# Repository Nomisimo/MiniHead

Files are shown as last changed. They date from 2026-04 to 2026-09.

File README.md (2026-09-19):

# 💡 Mini LED Moving Head

> A DIY mini LED moving head controller based on the ESP32-C3 microcontroller.

---

## 📋 Hardware

| Component | Model |
|---|---|
| Microcontroller | ESP32-C3 Super Mini |
| LED | WS2812B RGBW (1 pixel) |
| Pan servo | TS90MD |
| Tilt servo | TS90MD |

---

## 🚀 Quick Start

```bash
git clone https://github.com/Nomisimo/MiniHead.git
```

→ Current firmware: **[MiniHead](Firmware/MiniHead/README.md)**

---

## 📖 Wiki

- [Feature Map](https://github.com/Nomisimo/MiniHead/wiki/Feature-Map)
- [Firmware Versions](https://github.com/Nomisimo/MiniHead/wiki/Firmware-Versions)

---

## 🙏 Credits

- **cooke001** — [miniTheatreProject](https://github.com/cooke001/miniTheatreProject) (inspiration & foundation)
- **mathieucarbou** — [ESPAsyncWebServer](https://github.com/mathieucarbou/ESPAsyncWebServer) / [AsyncTCP](https://github.com/mathieucarbou/AsyncTCP) (IDF 5.x compatible forks)

> Art-Net™ is a trademark of Artistic Licence Holdings Ltd.

---

## 📜 License

**GNU General Public License v3.0** — [LICENSE](./LICENSE)

---

*Vibe coded with [Claude Code](https://claude.ai/code)*

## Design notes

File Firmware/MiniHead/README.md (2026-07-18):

# MiniHead Firmware — Modular v4.2

> Current recommended firmware for all new installations.  
> LittleFS JSON · ESPAsyncWebServer · Art-Net/DMX512 · Multi-Head UDP · BLE Provisioning

---

## Table of Contents

1. [Features](#1-features)
2. [Hardware](#2-hardware)
3. [Arduino IDE Setup](#3-arduino-ide-setup)
   - [3.1 Install Arduino IDE](#31-install-arduino-ide)
   - [3.2 Add ESP32 Board Package](#32-add-esp32-board-package)
   - [3.3 Install Libraries](#33-install-libraries)
   - [3.4 Board & Tools Settings](#34-board--tools-settings)
4. [Project Configuration — config.h](#4-project-configuration--configh)
5. [Flashing](#5-flashing)
6. [Code Structure](#6-code-structure)
   - [6.1 Entry Point](#61-entry-point--mainoino)
   - [6.2 Plugin System](#62-plugin-system)
   - [6.3 Core Hardware Layer](#63-core-hardware-layer--coreh)
   - [6.4 Plugin Overview](#64-plugin-overview)
7. [UI Themes](#7-ui-themes)
8. [HTTP API Reference](#8-http-api-reference)
   - [8.1 Control](#81-control)
   - [8.2 Cues & Sequencer](#82-cues--sequencer)
   - [8.3 Fixtures & Network](#83-fixtures--network)
   - [8.4 Art-Net Patch](#84-art-net-patch)
   - [8.5 Configuration](#85-configuration)
9. [UDP Protocol](#9-udp-protocol)
10. [Art-Net / DMX512](#10-art-net--dmx512)
11. [BLE Provisioning](#11-ble-provisioning)
12. [PC Leader App](#12-pc-leader-app)
13. [Art-Net Test Tool](#13-art-net-test-tool)
14. [Stored Files — LittleFS](#14-stored-files--littlefs)
15. [Serial Monitor — Boot Output](#15-serial-monitor--boot-output)

---

## 1. Features

| Feature | Detail |
|---|---|
| **Web UI** | Full control panel served directly from the ESP at `http://<ip>` — no app needed |
| **Multi-head network** | Leader/follower election by lowest MAC; PC Leader App always wins |
| **Cues + Sequencer** | Up to 32 saved scenes, per-fixture targeting, timed playback with loop |
| **Art-Net / DMX512** | Built-in WiFiUDP parser, 7-channel fixture footprint, no external library |
| **BLE Provisioning** | Zero-touch WiFi credential distribution via Bluetooth GATT |
| **LittleFS JSON storage** | All settings in human-readable `.json` files; survives firmware updates |
| **ESPAsyncWebServer** | Non-blocking HTTP; servo commands respond in < 5 ms |
| **WiFi multi-network** | Tries last-connected SSID first, falls back down a list |
| **Theme system** | Swap the full UI look by renaming a header file and reflashing |
| **Servo smoothing** | Exponential smoothing at 50 Hz with deadband — silent, jitter-free |
| **Debugger plugin** | Optional: log config UI + loop frequency, heap, FreeRTOS task stats over Serial |

---

## 2. Hardware

| Component | Model | Pin |
|---|---|---|
| Microcontroller | ESP32-C3 Super Mini (RISC-V, single-core) | — |
| LED | WS2812B RGBW, 1 pixel | GPIO 8 |
| Pan servo | SG90 | GPIO 2 |
| Tilt servo | SG90 | GPIO 3 |
| Power | 5 V, ≥ 1 A shared rail for LED + servos | — |

> **USB CDC:** The ESP32-C3 Super Mini uses an integrated USB serial bridge — no external USB-UART adapter needed. **USB CDC On Boot must be Enabled** in Arduino IDE (see §3.4).

---

## 3. Arduino IDE Setup

### 3.1 Install Arduino IDE

Download **Arduino IDE 2.x** from https://www.arduino.cc/en/software

### 3.2 Add ESP32 Board Package

1. **File → Preferences** (macOS: **Arduino IDE → Settings**)
2. Paste into *Additional boards manager URLs*:
   ```
   https://raw.githubusercontent.com/espressif/arduino-esp32/gh-pages/package_esp32_index.json
   ```
3. **Tools → Board → Boards Manager** → search `esp32` → install **"esp32" by Espressif Systems** version **3.x**

> ⚠️ **Version 3.x is required.** Version 2.x is not compatible with the async web server fork used here.

### 3.3 Install Libraries

#### Via Library Manager (`Tools → Manage Libraries`)

| Library | Author | Notes |
|---|---|---|
| **Adafruit NeoPixel** | Adafruit | RGBW LED driver |
| **ESP32Servo** | Kevin Harrington | Servo PWM on ESP32 |
| **ArduinoJson** | Benoit Blanchon | JSON for LittleFS files and API |

> **Remove if installed (no longer needed):**
> - **ArtnetWifi** — replaced with a custom WiFiUdp parser in `artnet_receiver.h` (no external library dependency)
> - **Adafruit DMA NeoPixel** — DMA variant for SAMD21/SAMD51 only; never applicable to ESP32-C3

#### Via ZIP Install — AsyncTCP + ESPAsyncWebServer

The standard Library Manager version of ESPAsyncWebServer is **incompatible with Arduino Core 3.x**. Use the **mathieucarbou fork** exclusively.

**Download these ZIPs:**

| Library | URL |
|---|---|
| AsyncTCP | https://github.com/mathieucarbou/AsyncTCP/archive/refs/heads/main.zip |
| ESPAsyncWebServer | https://github.com/mathieucarbou/ESPAsyncWebServer/archive/refs/heads/main.zip |

**Install:** `Sketch → Include Library → Add .ZIP Library…` — install **AsyncTCP first**, then ESPAsyncWebServer.

**Remove old versions first** (if previously installed via Library Manager): delete their folders from `~/Documents/Arduino/libraries/`.

#### Libraries that come with ESP32 Arduino Core (no install needed)

These are part of the ESP32 board package and available automatically:

- `WiFi.h`, `WiFiUdp.h` — WiFi STA/AP + UDP sockets
- `ESPmDNS.h` — mDNS (`minihead.local`)
- `DNSServer.h` — Captive portal DNS
- `LittleFS.h` — Flash file system
- `BLEDevice.h`, `BLEServer.h`, `BLEClient.h`, `BLEScan.h`, … — Bluetooth GATT (BLE provisioning)
- `freertos/FreeRTOS.h`, `task.h` — RTOS tasks (BLE provisioning sender)
- `mbedtls/aes.h`, `mbedtls/md.h` — Crypto (BLE provisioning)

### 3.4 Board & Tools Settings

Set these in the **Tools** menu before every upload:

| Setting | Value |
|---|---|
| **Board** | `ESP32C3 Dev Module` |
| **USB CDC On Boot** | `Enabled` ← **required for Serial Monitor** |
| **CPU Frequency** | `160 MHz` |
| **Flash Frequency** | `80 MHz` |
| **Flash Mode** | `QIO` |
| **Flash Size** | `4MB (32Mb)` |
| **Partition Scheme** | `Huge APP (3MB No OTA/1MB SPIFFS` |
| **Upload Speed** | `921600` |
| **Port** | your ESP32's USB port |

> **Partition Scheme is mandatory.** LittleFS uses the SPIFFS partition slot. Without this, the device boots but cannot save settings — cues, patches, and WiFi memory are lost on every reset.

**Finding your port:**
- macOS: `/dev/cu.usbmodem…` or `/dev/cu.SLAB_USBtoUART`
- Windows: `COM3`, `COM4`, … (Device Manager)
- Linux: `/dev/ttyUSB0` or `/dev/ttyACM0`

macOS CH34x driver (if port doesn't appear): https://github.com/WCHSoftGroup/ch34xser_macos

---

## 4. Project Configuration — config.h

`config.h` is **git-ignored** — copy the template first:

```bash
cp config.example.h config.h
```

`config.h` is the **only file you normally need to edit**. It controls which plugins are active and what WiFi networks to try. Here's the complete annotated file:

```cpp
// ── Plugin flags ──────────────────────────────────────────────────
// Uncomment to enable. Order here does NOT matter — plugins register
// themselves via static initializers. Execution order in main.ino is
// determined by the #include order below.

//#define PLUGIN_STARTUP_ANIMATION  // Servo sweep + color test on first boot
//#define PLUGIN_UDP_CONTROL        // Multi-head UDP discovery + leader election
//#define PLUGIN_ARTNET             // Art-Net / DMX512 receiver
//#define PLUGIN_DEBUGGER           // Log config UI + loop timing + heap stats (must be last)
//#define PLUGIN_BLE_PROVISION      // BLE GATT WiFi credential distribution

// ── WiFi network list ─────────────────────────────────────────────
// The ESP tries networks in this order (last-connected SSID gets
// priority on next boot). Leave empty if using BLE provisioning.
struct WifiCredential { const char* ssid; const char* password; };
static const WifiCredential WIFI_NETWORKS[] = {
  { "PrimarySSID",  "password1" },
  { "BackupSSID",   "password2" },  // optional fallback
};
static const int WIFI_NETWORK_COUNT =
    sizeof(WIFI_NETWORKS) / sizeof(WIFI_NETWORKS[0]);

// ── AP hotspot password ───────────────────────────────────────────
// Used when no known WiFi is reachable. Must be ≥ 8 chars, or "" for open.
#define AP_PASSWORD ""

// ── BLE Provisioning ─────────────────────────────────────────────
// 32 hex chars = 16-byte AES-128 key. All devices in the fleet must
// share the same key. Change before flashing — never leave as zeros.
#define PROVISION_KEY "00000000000000000000000000000000"
```

**WiFi boot sequence:**
1. Read `/wifi_saved.json` (BLE-provisioned credentials) and try alongside `WIFI_NETWORKS[]`
2. Read `/wifi_last.json` — try that SSID first if visible
3. Try remaining entries in order, then without scan filter (hidden SSIDs)
4. After 2 failed cycles → start AP hotspot `MiniHead-XXYY` at `192.168.4.1` *(Standalone mode only; UDP/Art-Net devices retry forever)*

**Changing config.h always requires a full re-upload** (it's compiled in). LittleFS data (cues, patches, names) is preserved across uploads.

---

## 5. Flashing

1. Connect ESP32-C3 via USB-C
2. Open `main/main.ino` in Arduino IDE
3. Verify Tools settings (§3.4) and select the correct port
4. Click **Upload** or press **Ctrl+U / Cmd+U**

Watch the console for:
```
Wrote 123456 bytes ...
Hash of data verified.
Hard resetting via RTS pin...
```

Open **Tools → Serial Monitor** at **115200 baud** and press the reset button. See §15 for expected output.

> Re-flash whenever you change `config.h`, pins, or any `#define`. LittleFS data survives.

---

## 6. Code Structure

```
main/
├── main.ino                         ← Entry point (setup + loop) — never touch this
├── config.h                         ← Your configuration (git-ignored)
├── config.example.h                 ← Template for config.h
├── core.h                           ← Hardware drivers: LED, servos, animations
├── core_globals.h                   ← extern declarations shared across plugins
├── plugin_registry.h                ← REGISTER_PLUGIN macro + _plugins[] table
└── plugins/
    ├── storage/
    │   └── storage.h                ← LittleFS mount + readJson/writeJson helpers
    ├── startup_animation/
    │   └── startup_animation.h      ← Servo sweep + color test (optional)
    ├── wifi/
    │   ├── wifi.h                   ← Plugin entry point
    │   ├── wifi_control.h           ← ESPAsyncWebServer, all HTTP routes, cues, sequencer
    │   ├── discovery.h              ← UDP beacon broadcast + leader/follower election
    │   ├── discovery_globals.h      ← Shared types: NodeRole, Peer, MAC, ports
    │   ├── discovery_stubs.h        ← Empty stubs when PLUGIN_UDP_CONTROL is off
    │   ├── html_page.h              ← Embedded main UI HTML (PROGMEM, layout only)
    │   ├── theme.h                  ← Active CSS theme (PROGMEM, served at GET /theme)
    │   └── log_config.h             ← Runtime log level struct + load/save (always included)
    ├── udp_control/
    │   ├── udp_control.h            ← Plugin entry point
    │   └── discovery.h              ← Leader election, peer table, UDP CMD dispatcher
    ├── artnet/
    │   ├── artnet.h                 ← Plugin entry point
    │   ├── artnet_globals.h         ← Structs, DMX_FOOTPRINT, ARTNET_PORT
    │   ├── artnet_receiver.h        ← WiFiUDP polling, DMX parsing, apply + relay
    │   ├── artnet_control.h         ← HTTP patch management routes
    │   └── artnet_panel_html.h      ← Art-Net panel HTML
    ├── ble_provision/
    │   ├── ble_provision.h          ← Full BLE GATT provisioning logic (SEEKER + SENDER)
    │   └── ble_provision_config.h   ← BLE service/characteristic UUIDs + timeouts
    ├── debugger/
    │   └── debugger.h               ← Log config HTTP UI + loop timing + heap stats (optional)
    └── shared/
        └── crypto.h                 ← AES-128-CBC + HMAC-SHA256 + key parser (shared)
```

### 6.1 Entry Point — `main.ino`

`main.ino` is intentionally minimal and **never needs to be edited** (plugins are added via `config.h`). What it does:

```
setup():
  core_setup()                → mount LittleFS, init LED + servos
  [ble_provision_pre_wifi()]  → SEEKER blocks here if no credentials (optional, BLE provisioning only)
  wifi_connectMulti()         → connect to WiFi or start AP mode
  WiFi.setSleep(false)          → disable modem sleep for low-latency UDP
  MDNS.begin("minihead")        → accessible as minihead.local
  for each plugin: setup()      → initialize all registered plugins

loop():
  DNS captive portal tick        → handles Android/iOS in AP mode
  core_loop()                   → servo smoothing, rainbow/demo animation
  for each plugin: loop()       → run all plugin loops (HTTP, Art-Net, discovery…)
```

### 6.2 Plugin System

Each plugin lives in its own folder and self-registers via a static C++ initializer before `setup()` runs:

```cpp
// At the bottom of every plugin header:
REGISTER_PLUGIN(wifi);
// expands to:
// static PluginRegistrar _wifi_reg(wifi_setup, wifi_loop);
```

The `PluginRegistrar` constructor appends `{setup, loop}` to the global `_plugins[]` array (max 8 entries). `main.ino` calls them all in registration order without knowing their names.

**To add a plugin:** uncomment its `#define` and `#include` in `config.h`.  
**To remove a plugin:** comment them out. The stubs header keeps link-time symbols valid.

### 6.3 Core Hardware Layer — `core.h`

`core.h` initializes the hardware and exposes global functions used by all plugins:

| Function | Description |
|---|---|
| `core_setup()` | Mount LittleFS, init NeoPixel, attach servos at 50 Hz |
| `core_loop()` | Servo smoothing (every 20 ms), rainbow hue cycle, demo sinusoid |
| `setLED(r, g, b, w)` | Set RGBW LED. No-op if color unchanged (saves NeoPixel interrupt) |
| `setPan(angle)` | Set pan target 0–270°. Smoothed exponentially at 50 Hz |
| `setTilt(angle)` | Set tilt target 0–270° |
| `applyCommand(String)` | Parse and apply a control string (see §9 command format) |

**Servo smoothing:** `next = current + 0.12 × (target − current)` — deadband 1.5° to stop hunting.

**Global state** (readable anywhere via `core_globals.h`):

| Variable | Type | Meaning |
|---|---|---|
| `curR/G/B/W` | `uint8_t` | Current LED color |
| `curPan/curTilt` | `int` | Current servo angle |
| `rainbowActive` | `bool` | Rainbow effect running |
| `demoActive` | `bool` | Demo sinusoid animation |
| `animSpeed` | `float` | Speed multiplier 0.1–3.0× |
| `wifiAPMode` | `bool` | Device is in AP hotspot mode |

### 6.4 Plugin Overview

| Plugin | `#define` | What it does |
|---|---|---|
| **wifi** | always on | HTTP server, web UI, cues, sequencer, leader redirect |
| **startup_animation** | `PLUGIN_STARTUP_ANIMATION` | Servo sweep + RGBW color test on boot |
| **udp_control** | `PLUGIN_UDP_CONTROL` | UDP discovery beacons, leader election, peer table, CMD relay |
| **artnet** | `PLUGIN_ARTNET` | Art-Net DMX512 receiver + HTTP patch management |
| **ble_provision** | `PLUGIN_BLE_PROVISION` | Zero-touch WiFi credential distribution via Bluetooth GATT |
| **debugger** | `PLUGIN_DEBUGGER` | Log config web UI (`/api/logconfig`) + loop stats, heap, FreeRTOS task table over Serial. **Must be last in `config.h`.** |

---

## 7. UI Themes

The web UI separates **layout** (never changes) from **theme** (all colors, fonts, and visual styles). The theme is a CSS file served by the ESP at `GET /theme`.

### Available theme files

| File | Design |
|---|---|
| `theme.h` | **Active theme.** Dark cyberpunk — cyan + purple accents, Share Tech Mono |

### How to switch themes

1. Replace the contents of `theme.h` with your custom CSS (or create a new file and rename it to `theme.h`)
2. Upload firmware

No other changes needed — `wifi_control.h` always serves `theme.h` at `GET /theme`.

### How themes work (CSS variables)

Every theme defines a `:root {}` block with these variables. Components reference only `var(--name)`:

```css
:root {
  /* Backgrounds */
  --bg:        #0a0a0f;   /* page background */
  --surface:   #13131a;   /* card / panel background */
  --surface2:  #1c1c26;   /* secondary surface, inputs */
  --border:    #2a2a3a;   /* dividers, input borders */

  /* Accent colors */
  --accent:    #00e5ff;   /* primary accent (cyan / blue) */
  --accent2:   #ff6b35;   /* secondary accent (orange) */
  --accent3:   #a855f7;   /* tertiary accent (purple) */

  /* Text */
  --text:      #e0e0f0;   /* primary text */
  --text-dim:  #6b6b8a;   /* labels, metadata */

  /* Status */
  --success:   #22c55e;   /* connected, Art-Net active */
  --danger:    #ef4444;   /* error, disconnect */

  /* Typography */
  --mono:      'Share Tech Mono', monospace;
  --sans:      'Barlow', sans-serif;
}
```

To create a custom theme: copy any theme file, rename it to `theme.h`, adjust the `:root` variables to taste, and reflash.

---

## 8. HTTP API Reference

All routes are available at `http://<esp-ip>/`. Responses are `application/json` unless noted.

In AP mode (`192.168.4.1`) the full API is available. Routes guarded by leader-check redirect followers to the leader IP/port.

---

### 8.1 Control

| Method | Path | Body (JSON) | Response | Description |
|---|---|---|---|---|
| `GET` | `/api/status` | — | `{"connected":true,"port":"WiFi","ip":"…","apMode":false,"apPasswordSet":false,"rainbowActive":false,"demoActive":false,"animSpeed":1.0}` | Current device state |
| `GET` | `/api/version` | — | `{"version":"4.2"}` | Firmware version |
| `POST` | `/api/send` | `{"command":"R:255,G:0,B:0,W:0,PAN:90,TILT:45","targets":["AA:BB:CC:DD:EE:FF"]}` | `{"status":"ok"}` | Send a control command. Omit `targets` or pass `[]` for broadcast to all |
| `POST` | `/api/rainbow` | `{"on":true}` | `{"status":"ok"}` | Start or stop the rainbow hue cycle |
| `POST` | `/api/demo` | `{"on":true}` | `{"status":"ok"}` | Start or stop the sinusoid demo animation |
| `POST` | `/api/animation/speed` | `{"speed":1.5}` | `{"status":"ok"}` | Set animation speed multiplier (0.1 – 3.0) |
| `POST` | `/api/blackout` | — | `{"status":"ok"}` | Immediate blackout — LED off, stop all effects |
| `POST` | `/api/ap/password` | `{"password":"mypassword"}` | `{"status":"ok","reconnect":true}` | Set AP hotspot password (≥ 8 chars). Empty string removes it |

**Command string format** (used in `POST /api/send` and UDP CMD):

```
R:0-255,G:0-255,B:0-255,W:0-255,PAN:0-270,TILT:0-270
RAINBOW:0|1
DEMO:0|1
SPEED:0.1-3.0
BLACKOUT
```

Fields are optional and can be combined: `R:255,PAN:90` sets red and pan without touching other channels.

---

### 8.2 Cues & Sequencer

A **cue** is a named scene: RGBW color + pan + tilt + a list of fixture targets.

| Method | Path | Body (JSON) | Response | Description |
|---|---|---|---|---|
| `GET` | `/api/cues` | — | `[{"id":1700000000,"name":"Red Wash","r":255,"g":0,"b":0,"w":0,"pan":90,"tilt":45,"fixTargets":[1,2],"targetCount":2}, …]` | List all saved cues |
| `POST` | `/api/cues` | `{"name":"My Cue","r":255,"g":128,"b":0,"w":0,"pan":90,"tilt":45,"fixTargets":[1]}` | `{"status":"ok","id":1700000001}` | Save current state as a new cue |
| `POST` | `/api/cues/:id/fire` | — | `{"status":"ok"}` | Fire cue immediately to its targets |
| `PUT` | `/api/cues/:id/targets` | `{"fixTargets":[1,2,3]}` | `{"status":"ok"}` | Update which fixtures a cue targets |
| `PUT` | `/api/cues/reorder` | `{"order":[id3,id1,id2]}` | `{"status":"ok"}` | Reorder cues (affects sequencer playback order) |
| `DELETE` | `/api/cues/:id` | — | `{"status":"ok"}` | Delete cue by ID |
| `POST` | `/api/sequencer/start` | `{"interval_ms":2000,"loop":true,"cue_ids":[id1,id2,id3]}` | `{"status":"ok"}` | Start automatic sequence playback |
| `POST` | `/api/sequencer/stop` | — | `{"status":"ok"}` | Stop sequencer |
| `GET` | `/api/sequencer/status` | — | `{"running":false}` | Is sequencer currently playing? |

**Cue limits:** max 32 cues, max 16 fixture targets per cue. `fixTargets:[]` or `fixTargets:[0]` targets all known fixtures. Cues persist in `/cues.json` across reboots.

---

### 8.3 Fixtures & Network

| Method | Path | Body (JSON) | Response | Description |
|---|---|---|---|---|
| `GET` | `/api/heads` | — | `[{"mac":"AA:BB:CC:DD:EE:FF","ip":"192.168.1.100","fixID":1,"name":"Head 1","role":"LEADER","online":true}, …]` | All known heads including self |
| `GET` | `/api/fixtures` | — | `[{"id":1,"name":"Head 1","mac":"AA:BB:CC:DD:EE:FF","ip":"192.168.1.100","online":true}, …]` | Fixtures indexed by fixID |
| `POST` | `/api/heads/:mac/identify` | `{"on":true}` | `{"status":"ok"}` | Flash LED white for 2 s to identify a head |
| `POST` | `/api/heads/:mac/fixid` | `{"fixID":2}` | `{"status":"ok"}` | Set fixture ID on a remote head |
| `POST` | `/api/heads/:mac/name` | `{"name":"Stage Left"}` | `{"status":"ok"}` | Set display name on a remote head |

---

### 8.4 Art-Net Patch

Only available when `PLUGIN_ARTNET` is enabled.

| Method | Path | Body (JSON) | Response | Description |
|---|---|---|---|---|
| `GET` | `/api/artnet/status` | — | `{"active":true,"patchCount":1,"r":255,"g":0,"b":0,"w":0,"pan":90,"tilt":45}` | Art-Net status + live DMX output |
| `GET` | `/api/artnet/patch` | — | `[{"fixID":1,"universe":1,"startAddr":1}]` | Current patch assignments |
| `POST` | `/api/artnet/patch` | `{"universe":1,"startAddr":1}` | `{"status":"ok"}` | Set own patch |
| `PUT` | `/api/artnet/patch/*` | `{"universe":1,"startAddr":8}` | `{"status":"ok"}` | Update universe/address (pass -1 to leave unchanged) |
| `DELETE` | `/api/artnet/patch` | — | `{"status":"ok"}` | Clear all patches |
| `POST` | `/api/artnet/patch/bulk` | `{"universe":1,"startAddr":1,"count":4,"firstFixID":1}` | `{"status":"ok"}` | Auto-assign patches to N consecutive fixtures starting at firstFixID |

> Universe must be **1–32767**. Universe 0 is rejected at all API layers.

**DMX fixture footprint (7 channels):**

| Ch offset | Parameter | Range |
|---|---|---|
| 0 | Master dimmer | 0–255 |
| 1 | Red | 0–255 |
| 2 | Green | 0–255 |
| 3 | Blue | 0–255 |
| 4 | White | 0–255 |
| 5 | Pan | 0–255 → 0–270° |
| 6 | Tilt | 0–255 → 0–270° |

---

### 8.5 Configuration

These routes always operate on the local device (no leader redirect):

| Method | Path | Body (JSON) | Response | Description |
|---|---|---|---|---|
| `POST` | `/api/config/fixid` | `{"fixID":1}` | `{"status":"ok"}` | Set this device's fixture ID (persists to `/discovery.json`) |
| `POST` | `/api/config/name` | `{"name":"Stage Left"}` | `{"status":"ok"}` | Set this device's display name |
| `GET` | `/api/logconfig` | — | log config JSON | Get runtime log levels *(requires `PLUGIN_DEBUGGER`)* |
| `POST` | `/api/logconfig` | log config JSON | `{"status":"ok"}` | Set runtime log levels *(requires `PLUGIN_DEBUGGER`)* |

---

## 9. UDP Protocol

When `PLUGIN_UDP_CONTROL` is enabled, devices broadcast discovery beacons and listen for commands.

### Discovery beacon — port 4210

Sent every 2000 ms as a UTF-8 string broadcast to the subnet:

```
MINIHEAD|AA:BB:CC:DD:EE:FF|192.168.1.100|1|LEADER|Head 1|UDP|100
          ─────MAC──────── ──────IP───── ^ ──────  ──────  ───  ───
                                         fixID    name    mode  priority
```

`mode` is `UDP` or `ARTNET`. `role` is `LEADER` or `FOLLOWER`. `priority`: `0` = PC App, `100` = ESP. Older firmware without the priority field defaults to `100` for backward compatibility.

A peer is considered stale after **90 seconds** without a beacon.

### Commands — port 4211

```
CMD|AA:BB:CC:DD:EE:FF|R:255,G:0,B:0,W:0,PAN:90,TILT:45
     ──target MAC───  ──────command string──────────────
```

Special packets:

```
IDENTIFY_ON|AA:BB:CC:DD:EE:FF    → flash LED white for 2 s
IDENTIFY_OFF|AA:BB:CC:DD:EE:FF   → stop identify immediately
SETPATCH|fixID|universe|addr      → set Art-Net patch on target
```

### Leader election

1. Each device listens on port 4210 for 4 seconds at boot
2. Lowest **priority** wins (`0` = PC App, `100` = ESP); MAC is the tiebreaker among equal-priority nodes — the PC App always beats any ESP
3. Followers redirect their web UI requests to the leader (port 8080 if PC App, port 80 if ESP)
4. If leader goes silent for > 90 s, a new election happens after a 10 s hold

---

## 10. Art-Net / DMX512

Enable with `#define PLUGIN_ARTNET` in `config.h`.

- Listens on UDP port **6454** (Art-Net standard)
- Receives **ArtDMX** packets (opcode `0x5000`)
- Applies channels to the local fixture based on the **patch** (universe + start address)
- Relays commands to peer heads via UDP CMD when Art-Net controls multiple fixtures
- Times out after **8 seconds** without a packet → marks Art-Net inactive, re-enables manual control
- Status bar in the web UI turns green when Art-Net is active; manual sliders gray out

**Setup:**
1. Enable `PLUGIN_ARTNET`, compile, flash
2. Open `http://<esp-ip>` → Art-Net panel → set Universe and Start Address
3. Send Art-Net from a controller (PC App, test tool, DMX desk, etc.)

---

## 11. BLE Provisioning

Enable with `#define PLUGIN_BLE_PROVISION` in `config.h`.

This allows devices with **no WiFi credentials** (empty `WIFI_NETWORKS[]`) to receive the SSID and password wirelessly from a device that is already connected — no USB cable or AP needed for new heads. Uses Bluetooth GATT (frequency-hopping 2.4 GHz) instead of ESP-NOW, so there is **no WiFi channel constraint**.

### Roles

| Role | Condition | Behaviour |
|---|---|---|
| **SEEKER** | `WIFI_NETWORK_COUNT == 0` and no `/wifi_provision.json` and no `/wifi_saved.json` | BLE scan loop; on finding a SENDER: connects, reads characteristic, verifies HMAC, decrypts, saves credentials to `/wifi_provision.json`, reboots |
| **SENDER** | Connected to WiFi via STA | Starts a GATT server in a background task; advertises encrypted SSID+PW for `PROVISION_SENDER_MS`; then deinits BLE automatically |

### Security

- **PROVISION_KEY** (set in `config.h`, 32 hex chars) is used as AES-128-CBC key and HMAC-SHA256 key
- Only devices with the matching key can decrypt the payload
- SSID+PW are AES-128-CBC encrypted with a fresh random IV per payload
- HMAC-SHA256 covers the full payload — integrity and authentication
- Key is never transmitted — only used locally for crypto operations

### Setup

1. Set a real key in `config.h`:
   ```cpp
   #define PROVISION_KEY "a1b2c3d4e5f6a7b8c9d0e1f2a3b4c5d6"
   ```
2. Uncomment `#define PLUGIN_BLE_PROVISION`
3. Flash **all devices** with the same binary
4. One device needs `WIFI_NETWORKS[]` filled in (it becomes the SENDER)
5. Other devices start with empty `WIFI_NETWORKS[]` → they become SEEKERs

### Boot flow with provisioning enabled

```
Device with credentials:            Device without credentials (first time):
  boot → ble_provision_pre_wifi()     boot → ble_provision_pre_wifi()
  → already has creds → no-op         → SEEKER: BLE scan loop
  wifi_connectMulti() → connected       ↓ finds SENDER GATT service
  plugin setup() → SENDER task starts   ↓ reads + verifies payload
  advertises encrypted creds → →      credentials verified (HMAC + AES decrypt)
  stops after PROVISION_SENDER_MS     saved to /wifi_provision.json → reboot
                                        boot → wifi_connectMulti()
                                          reads /wifi_provision.json
                                          copies to /wifi_saved.json (permanent)
                                          deletes /wifi_provision.json
                                        → connected ✓
                                        All subsequent boots: uses /wifi_saved.json
                                        plugin_setup() → also SENDER now
```

---

## 12. PC Leader App

`PC App/server.py` — Python/Flask server that acts as the permanent network leader. ESP devices detect it and yield to it automatically.

### Requirements

```bash
pip install flask
```

### Start

```bash
cd "PC App"
python3 server.py
```

Open **http://localhost:8080**

### What it does

| Function | Detail |
|---|---|
| Leader beacon | UDP broadcast every 1 s → ESP yields to PC |
| Peer discovery | Reads ESP beacons → builds peer table |
| Full web UI | Control all heads from `http://localhost:8080` |
| Art-Net sniffer | Monitors UDP 6454 for live DMX |
| Patch push | Sends `SETPATCH` UDP to ESP when patch changes |
| Auto-redirect | Visiting `http://<esp-ip>` while PC App is running redirects to `http://127.0.0.1:8080` |

---

## 13. Art-Net Test Tool

`PC APP/artnet_test.py` — standalone DMX sender with a browser UI for testing fixtures.

```bash
pip install flask
python3 artnet_test.py                             # broadcast
python3 artnet_test.py 192.168.1.100 0 1           # unicast to IP, universe 0, addr 1
python3 artnet_test.py 192.168.1.255 0 1 --bind 192.168.1.50  # force outgoing interface
```

Open **http://localhost:8765**

| Terminal key | Action |
|---|---|
| `SPACE` | Toggle demo mode |
| `n` | Toggle rainbow |
| `0` | Blackout |
| `f` | Full white |
| `p / P` | Pan ± 10 |
| `t / T` | Tilt ± 10 |
| `r/g/b/w` / `R/G/B/W` | Color channel ± 10 |
| `m / M` | Master ± 10 |
| `q` | Quit |

---

## 14. Stored Files — LittleFS

All files survive firmware uploads. To wipe, use **Tools → ESP32 Sketch Data Upload** with an empty data folder, or call `LittleFS.format()` once.

| File | Format | Contents |
|---|---|---|
| `/wifi_last.json` | `{"ssid":"YourSSID"}` | Last successfully connected SSID |
| `/wifi_provision.json` | `{"ssid":"…","pass":"…"}` | One-time BLE provisioning transport — deleted on first successful connect after credentials are copied to `/wifi_saved.json` |
| `/wifi_saved.json` | `{"ssid":"…","pass":"…"}` | Permanent BLE-provisioned credentials — used on every boot like a runtime `WIFI_NETWORKS[]` entry |
| `/discovery.json` | `{"fixID":1,"name":"Head 1"}` | Fixture ID and display name |
| `/cues.json` | JSON array | Up to 32 saved cues |
| `/artnet.json` | JSON array | Art-Net patch assignments |
| `/config.json` | `{"apPassword":"…"}` | AP password override (set via API) |

---

## 15. Serial Monitor — Boot Output

Set baud to **115200**. Press the reset button after opening.

**Successful STA connect:**
```
[Storage] LittleFS OK
[Core] LED + Servos ready
[WiFi] Scanning...
[WiFi] Connected: YourSSID  IP: 192.168.1.100
[Discovery] MAC: AA:BB:CC:DD:EE:FF  FixID: 1
[Discovery] Listening 4 s for existing leader...
[Discovery] ** I am the LEADER **
[WiFi] Async server started
[ArtNet] Listening on port 6454
```

**AP mode fallback:**
```
[WiFi] All networks failed (2/2)
[WiFi] AP mode — SSID: MiniHead-EEFF  IP: 192.168.4.1
[WiFi] Captive portal DNS started
[WiFi] mDNS: minihead.local
```

**SEEKER provisioning (first boot, no credentials):**
```
[PROVISION] No credentials — SEEKER mode (BLE scan)
[PROVISION] SEEKER BLE scan...
[PROVISION] SENDER found: AA:BB:CC:DD:EE:FF
[PROVISION] Payload received 124 bytes — verifying
[PROVISION] Credentials OK — SSID: YourSSID
[Storage] /wifi_provision.json — written
[PROVISION] Saved — rebooting
--- (reboot) ---
[WiFi] Trying "YourSSID" .....
[WiFi] Connected: YourSSID  IP: 192.168.1.101
```

**Art-Net active:**
```
[ArtNet] Fix#1  M=255 R=216 G=255 B=0 W=0  PAN=41 TILT=125
[ArtNet] Timeout — inactive
```

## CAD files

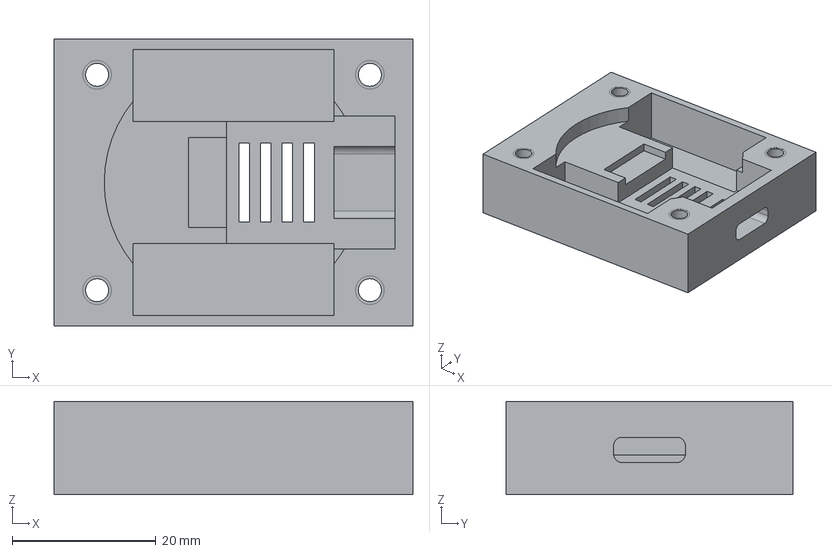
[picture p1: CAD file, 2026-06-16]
3D Models/202606072040-Base-Bottom.step
50.0 x 40.0 x 13.0 mm

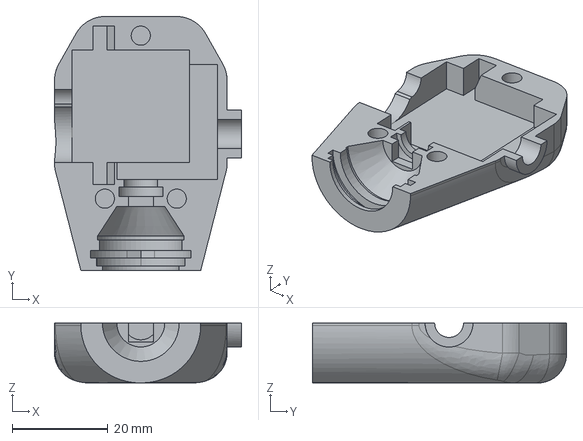
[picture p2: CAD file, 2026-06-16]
3D Models/202606072030-Head-Bottom.step
39.0 x 53.0 x 12.5 mm

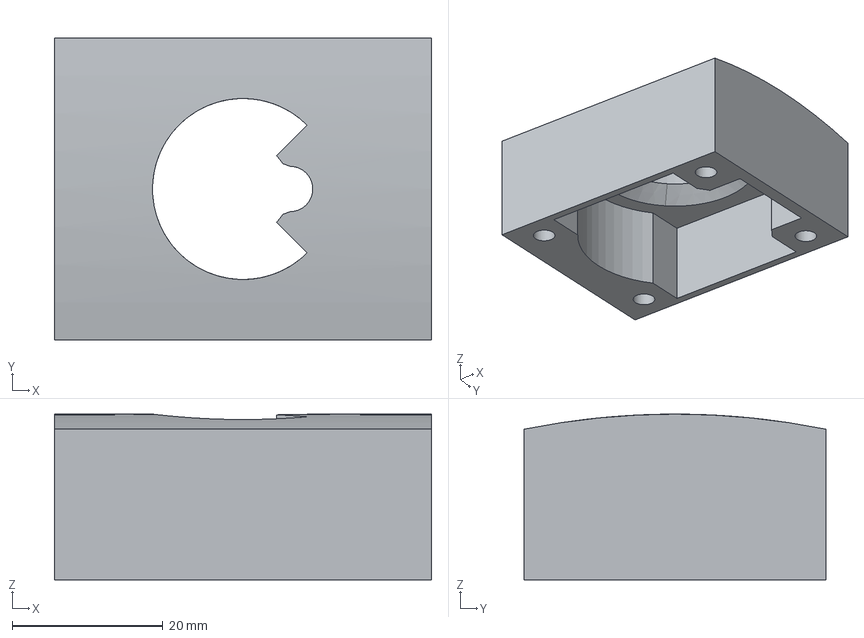
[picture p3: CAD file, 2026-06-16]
3D Models/202606072040-Base-Top.step
50.0 x 40.0 x 22.0 mm

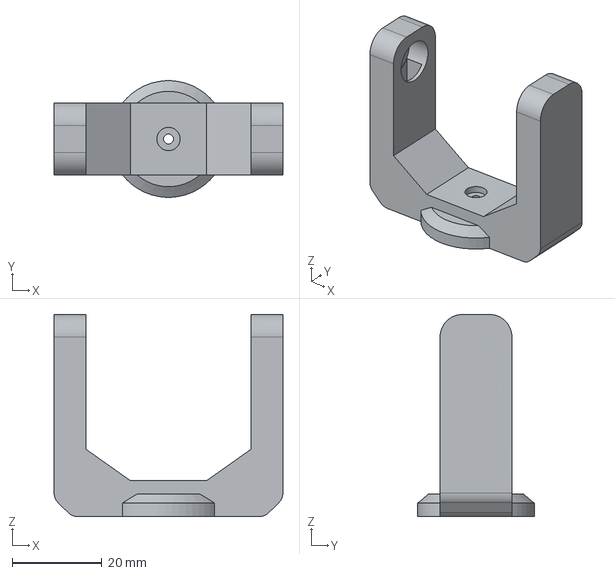
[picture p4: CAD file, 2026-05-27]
3D Models/202605122300-Yoke.step
51.0 x 26.0 x 45.0 mm

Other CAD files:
3D Models/202606072030-Head-Top.step
3D Models/202605312225-Base-Bottom.step
3D Models/202605312225-Head-Top.step
3D Models/202605312225-Head-Bottom.step
3D Models/202605312225-Base-Top.step

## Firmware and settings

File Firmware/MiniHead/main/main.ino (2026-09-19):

/*
 * =====================================================
 *   NANO MOVING LIGHT — Modular Edition
 *   Hardware : ESP32-C3 Super Mini
 * =====================================================
 * main.ino — never needs to be touched.
 * Add/remove plugins in config.h only.
 * =====================================================
 */

#include "config.h"
#include <ESPmDNS.h>
#include <DNSServer.h>

SET_LOOP_TASK_STACK_SIZE(16384);  // default is 8192, double it

static DNSServer _dnsServer;

// ── WiFi multi-network helpers ────────────────────────────────────

static bool wifi_ssidVisible(const char* ssid, int n) {
  for (int i = 0; i < n; i++)
    if (WiFi.SSID(i) == ssid) return true;
  return false;
}

static bool wifi_tryConnect(const char* ssid, const char* pass, unsigned long tms = 8000) {
  Serial.printf("[WiFi] Trying \"%s\" ", ssid);
  WiFi.begin(ssid, pass);
  unsigned long t = millis();
  while (WiFi.status() != WL_CONNECTED && millis() - t < tms) {
    unsigned long tickEnd = millis() + 500;
    while (millis() < tickEnd) { sled_wifiConnect(millis()); delay(20); }
    Serial.print(".");
  }
  Serial.println();
  if (WiFi.status() == WL_CONNECTED) {
    Serial.printf("[WiFi] Connected: %s  IP: %s\n", ssid, WiFi.localIP().toString().c_str());
    return true;
  }
  Serial.printf("[WiFi] Failed: %s\n", ssid);
  WiFi.disconnect(true);
  delay(200);
  return false;
}

static void wifi_saveLastSSID(const char* ssid) {
  JsonDocument doc;
  doc["ssid"] = ssid;
  storage_writeJson("/wifi_last.json", doc);
}

static void wifi_saveCreds(const char* ssid, const char* pass) {
  JsonDocument doc;
  doc["ssid"] = ssid;
  doc["pass"] = pass;
  storage_writeJson("/wifi_saved.json", doc);
}

// ── AP fallback ───────────────────────────────────────────────────
// Called when wifi_connectMulti() fails twice. Starts an open hotspot
// so the user can still reach the web UI without a known network.
static void wifi_startAPMode() {
  // Load AP password from /config.json (overrides config.h default if set)
  String apPw = AP_PASSWORD;
  { JsonDocument cfg;
    if (storage_readJson("/config.json", cfg) && cfg["apPassword"].is<const char*>())
      apPw = String(cfg["apPassword"].as<const char*>()); }

  // Read base MAC directly from eFuse — hardware-permanent, never changes,
  // works regardless of WiFi mode or connection state.
  char ssid[32];
  snprintf(ssid, sizeof(ssid), "MiniHead-%02X%02X", deviceMAC[4], deviceMAC[5]);

  WiFi.disconnect(true);
  delay(200);
  WiFi.mode(WIFI_AP);

  if (apPw.length() >= 8) WiFi.softAP(ssid, apPw.c_str());
  else                     WiFi.softAP(ssid);
  wifiAPMode    = true;
  apPasswordSet = (apPw.length() >= 8);

  IPAddress apIP = WiFi.softAPIP();
  Serial.printf("[WiFi] AP mode — SSID: %s  IP: %s\n", ssid, apIP.toString().c_str());

  // DNS server: answer ALL queries with our IP → captive portal on any URL
  _dnsServer.start(53, "*", apIP);
  Serial.println("[WiFi] Captive portal DNS started");

  // mDNS: accessible as minihead.local in addition to 192.168.4.1
  if (MDNS.begin("minihead")) {
    MDNS.addService("http", "tcp", 80);
    Serial.println("[WiFi] mDNS: minihead.local");
  }

  sled_apMode();  // triple red flash → solid red (stays; no ArtNet in AP mode)
}

static void wifi_connectMulti() {
  WiFi.mode(WIFI_STA);
  WiFi.disconnect(true);
  delay(200);

#ifdef PLUGIN_BLE_PROVISION
  // First-boot provisioning: save credentials permanently, then discard the transport file.
  { JsonDocument provDoc;
    if (storage_readJson("/wifi_provision.json", provDoc)) {
      const char* s = provDoc["ssid"] | "";
      const char* p = provDoc["pass"] | "";
      if (strlen(s) > 0 && strlen(p) > 0) {
        wifi_saveCreds(s, p);          // persist to /wifi_saved.json for all future boots
        LittleFS.remove("/wifi_provision.json");
      }
    }
  }
#endif

  // Load saved (BLE-provisioned) credential — treated identically to WIFI_NETWORKS[] entries.
  String savedSSID = "", savedPass = "";
  { JsonDocument savedDoc;
    if (storage_readJson("/wifi_saved.json", savedDoc)) {
      savedSSID = String(savedDoc["ssid"] | "");
      savedPass = String(savedDoc["pass"] | "");
    }
  }

  // Load networks added via the web UI (Saved Networks panel).
  loadWifiNetworksFromFlash();

  // Combine all three sources into one list — WIFI_NETWORKS[], the
  // BLE-provisioned credential, and user-added networks — so the
  // scan/retry logic below only has to iterate a single array.
  WifiCredential runtimeNets[WIFI_NETWORK_COUNT + 1 + MAX_SAVED_NETWORKS];
  int runtimeCount = 0;
  for (int i = 0; i < WIFI_NETWORK_COUNT; i++) runtimeNets[runtimeCount++] = WIFI_NETWORKS[i];
  if (savedSSID.length() > 0) runtimeNets[runtimeCount++] = { savedSSID.c_str(), savedPass.c_str() };
  for (int i = 0; i < savedNetworkCount; i++) runtimeNets[runtimeCount++] = { savedNetworks[i].ssid, savedNetworks[i].pass };

  int failCycles = 0;

  while (true) {
    // Read last-connected SSID from flash
    String lastSSID = "";
    JsonDocument lastDoc;
    if (storage_readJson("/wifi_last.json", lastDoc))
      lastSSID = String(lastDoc["ssid"] | "");

    // Scan
    Serial.println("[WiFi] Scanning...");
    int found = WiFi.scanNetworks();
    Serial.printf("[WiFi] %d network(s) found\n", found);

    // 1. Try last-connected first (only if visible)
    if (lastSSID.length() > 0) {
      for (int i = 0; i < runtimeCount; i++) {
        if (lastSSID == runtimeNets[i].ssid && wifi_ssidVisible(runtimeNets[i].ssid, found)) {
          if (wifi_tryConnect(runtimeNets[i].ssid, runtimeNets[i].password)) {
            wifi_saveLastSSID(runtimeNets[i].ssid);
            return;
          }
        }
      }
    }

    // 2. Try remaining visible networks in list order
    for (int i = 0; i < runtimeCount; i++) {
      if (lastSSID == runtimeNets[i].ssid) continue;  // already tried above
      if (!wifi_ssidVisible(runtimeNets[i].ssid, found)) continue;
      if (wifi_tryConnect(runtimeNets[i].ssid, runtimeNets[i].password)) {
        wifi_saveLastSSID(runtimeNets[i].ssid);
        return;
      }
    }

    // 3. No known SSID visible — try all without scan filter
    bool anyVisible = false;
    for (int i = 0; i < runtimeCount; i++)
      if (wifi_ssidVisible(runtimeNets[i].ssid, found)) { anyVisible = true; break; }

    if (!anyVisible) {
      Serial.println("[WiFi] No known SSIDs visible — trying all without scan filter...");
      for (int i = 0; i < runtimeCount; i++) {
        if (wifi_tryConnect(runtimeNets[i].ssid, runtimeNets[i].password)) {
          wifi_saveLastSSID(runtimeNets[i].ssid);
          return;
        }
      }
    }

    failCycles++;

    // AP fallback only in Standalone mode (no UDP, no Art-Net).
    // UDP and Art-Net devices must stay on the network — they keep retrying.
#if !defined(PLUGIN_UDP_CONTROL) && !defined(PLUGIN_ARTNET)
    if (failCycles >= 2) {
      wifi_startAPMode();
      return;   // proceed with setup() in AP mode
    }
#endif

    Serial.printf("[WiFi] All networks failed (%d) — retrying...\n", failCycles);

#ifdef PLUGIN_BLE_PROVISION
    ble_provision_pre_wifi();
    if (runtimeCount > 0) {
      unsigned long waitEnd = millis() + 10000;
      while (millis() < waitEnd) { sled_wifiRetry(millis()); delay(50); }
    }
#else
    { unsigned long waitEnd = millis() + 10000;
      while (millis() < waitEnd) { sled_wifiRetry(millis()); delay(50); } }
#endif
  }
}

// ── Arduino entry points ──────────────────────────────────────────

uint8_t deviceMAC[6];  // hardware STA MAC — read once before any WiFi mode changes

void setup() {
  Serial.begin(115200);
  core_setup();             // mounts LittleFS — must run before wifi_connectMulti
  sled_bootInit();          // orange solid — hardware alive

  // Read MAC before any WiFi mode changes — result is stable regardless of
  // whether the device ends up in STA or AP mode.
  WiFi.mode(WIFI_STA);
  WiFi.macAddress(deviceMAC);
  WiFi.mode(WIFI_OFF);

#ifdef PLUGIN_BLE_PROVISION
  ble_provision_pre_wifi();  // SEEKER: BLE scan loop; reboots if provisioned, returns on timeout
#endif

  wifi_connectMulti();      // blocks until connected (or starts AP mode)

  // Disable WiFi modem sleep — without this the radio powers down between
  // beacon intervals and drops ~60% of incoming UDP packets (ArtNet etc.).
  WiFi.setSleep(false);
  Serial.println("[WiFi] Modem sleep disabled (low-latency UDP mode)");

  // mDNS for STA mode — accessible as minihead.local on the local network
  if (!wifiAPMode) {
    if (MDNS.begin("minihead")) {
      MDNS.addService("http", "tcp", 80);
      Serial.println("[WiFi] mDNS: minihead.local");
    }
  }

  for (int i = 0; i < _pluginCount; i++)
    _plugins[i].setup();

  sled_bootDone();  // LED off — ArtNet/UDP takes over from here
}

void loop() {
  // Process DNS in AP/captive-portal mode
  if (wifiAPMode) _dnsServer.processNextRequest();

  // WiFi watchdog — detect prolonged disconnection and trigger a full reconnect.
  // Checks every WIFI_WATCHDOG_INTERVAL_MS; reconnects after WIFI_WATCHDOG_MISSES
  // consecutive misses (default: 3 × 15 s = 45 s total outage before reconnect).
  if (!wifiAPMode) {
    static unsigned long _wifiCheckAt = 0;
    static uint8_t       _wifiMisses  = 0;
    if (millis() > _wifiCheckAt) {
      _wifiCheckAt = millis() + WIFI_WATCHDOG_INTERVAL_MS;
      if (WiFi.status() != WL_CONNECTED) {
        _wifiMisses++;
        Serial.printf("[WiFi] Watchdog: disconnected (miss %u/%u)\n",
                      _wifiMisses, WIFI_WATCHDOG_MISSES);
        if (_wifiMisses >= WIFI_WATCHDOG_MISSES) {
          Serial.println("[WiFi] Watchdog: triggering full reconnect");
          _wifiMisses = 0;
          wifi_connectMulti();
        }
      } else {
        _wifiMisses = 0;
      }
    }
  }

  core_loop();
  for (int i = 0; i < _pluginCount; i++)
    _plugins[i].loop();
}

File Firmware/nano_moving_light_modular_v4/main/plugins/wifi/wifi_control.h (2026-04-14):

#pragma once

// ── WiFi Control Plugin (v4) ─────────────────────────────────────
// Handles: HTTP server, all API endpoints, cue storage, sequencer
// Runs when nodeRole == ROLE_STANDALONE (started/stopped by discovery.h)
// Depends on: core.h, discovery_globals.h, udp_control.h
// ─────────────────────────────────────────────────────────────────

#include <WiFi.h>
#include <WebServer.h>
#include <ArduinoJson.h>
#include <Preferences.h>
#include "html_page.h"
#include "core_globals.h"
#include "discovery_panel_html.h"
#include "discovery_globals.h"
#include "udp_control.h"
#include "../artnet/artnet_panel_html.h"

#define MAX_CUES         32
#define MAX_TARGETS      16   // max FixID targets per cue
#define CUES_NVS_VERSION 2    // bump when Cue struct changes

WebServer server(80);
Preferences prefs;

struct Cue {
  unsigned long id;
  char name[32];
  uint8_t r, g, b, w;
  int pan, tilt;
  int fixTargets[MAX_TARGETS];
  int targetCount;
};
Cue cues[MAX_CUES];
int cueCount = 0;

bool seqRunning = false;
unsigned long seqInterval = 1000;
bool seqLoop = true;
unsigned long seqIds[MAX_CUES];
int seqIdCount = 0;
int seqIndex = 0;
unsigned long lastSeqStep = 0;

// ── Flash storage ─────────────────────────────────────────────────

void saveCuesToFlash() {
  prefs.begin("cues", false);
  prefs.putInt("version", CUES_NVS_VERSION);
  prefs.putInt("count", cueCount);
  for (int i=0; i<cueCount; i++)
    prefs.putBytes(("c"+String(i)).c_str(), &cues[i], sizeof(Cue));
  prefs.end();
}

void loadCuesFromFlash() {
  prefs.begin("cues", false);
  if (prefs.getInt("version", 0) != CUES_NVS_VERSION) {
    prefs.clear();
    prefs.putInt("version", CUES_NVS_VERSION);
    prefs.end();
    cueCount = 0;
    Serial.println("[WiFi] Cue store migrated — old cues cleared");
    return;
  }
  cueCount = prefs.getInt("count", 0);
  if (cueCount > MAX_CUES) cueCount = 0;
  for (int i=0; i<cueCount; i++)
    prefs.getBytes(("c"+String(i)).c_str(), &cues[i], sizeof(Cue));
  prefs.end();
}

// ── Helpers ───────────────────────────────────────────────────────

void sendJson(int code, const String& json) {
  server.sendHeader("Access-Control-Allow-Origin", "*");
  server.send(code, "application/json", json);
}

// artnet_control.h needs server + sendJson — include after they're defined
#include "../artnet/artnet_control.h"

String fixTargetsToJson(const Cue& c) {
  String s = "[";
  for (int i=0; i<c.targetCount; i++) { if (i>0) s+=","; s+=String(c.fixTargets[i]); }
  s+="]"; return s;
}

String cueToJson(const Cue& c) {
  return "{\"id\":" + String(c.id) +
    ",\"name\":\"" + String(c.name) + "\"" +
    ",\"r\":"   + c.r   + ",\"g\":" + c.g +
    ",\"b\":"   + c.b   + ",\"w\":" + c.w +
    ",\"pan\":" + c.pan + ",\"tilt\":" + c.tilt +
    ",\"fixTargets\":" + fixTargetsToJson(c) + "}";
}

// ── Fire a cue to all its targets ────────────────────────────────

void fireCueToTargets(const Cue& c) {
  String cmd = "R:" + String(c.r) + ",G:" + String(c.g) +
               ",B:" + String(c.b) + ",W:" + String(c.w) +
               ",PAN:" + String(c.pan) + ",TILT:" + String(c.tilt);

  bool toAll = (c.targetCount == 0) || (c.targetCount == 1 && c.fixTargets[0] == 0);
  if (toAll) {
    rainbowActive = false;
    applyCommand(cmd);
    udp_broadcastCommand(cmd.c_str());
    return;
  }

  for (int t = 0; t < c.targetCount; t++) {
    int fid = c.fixTargets[t];
    if (ownFixID > 0 && ownFixID == fid) { rainbowActive = false; applyCommand(cmd); }
    for (int i = 0; i < peerCount; i++) {
      if (peers[i].active && peers[i].fixID == fid) {
        udp_sendCommand(peers[i].ip, peers[i].mac, cmd.c_str());
        break;
      }
    }
  }
}

// ── Route handlers ────────────────────────────────────────────────

// ── Mode endpoint ─────────────────────────────────────────────────
void handleMode() {
  const char* m =
    (nodeRole == ROLE_STANDALONE) ? "standalone" :
    (nodeRole == ROLE_FOLLOWER)   ? "follower"   : "unknown";
  sendJson(200, String("{\"mode\":\"") + m + "\"}");
}

// ── Cue Export / Import ───────────────────────────────────────────

void handleExportCues() {
  String json = "[";
  for (int i = 0; i < cueCount; i++) { if (i > 0) json += ","; json += cueToJson(cues[i]); }
  json += "]";
  server.sendHeader("Access-Control-Allow-Origin", "*");
  server.sendHeader("Content-Disposition", "attachment; filename=\"cues.json\"");
  server.send(200, "application/json", json);
}

void handleImportCues() {
  JsonDocument doc;
  if (deserializeJson(doc, server.arg("plain"))) { sendJson(400, "{\"status\":\"error\",\"message\":\"Bad JSON\"}"); return; }
  JsonArray arr = doc.as<JsonArray>();
  if (arr.isNull()) { sendJson(400, "{\"status\":\"error\",\"message\":\"Expected array\"}"); return; }
  bool replace = (server.arg("mode") != "append");
  if (replace) cueCount = 0;
  for (JsonObject obj : arr) {
    if (cueCount >= MAX_CUES) break;
    Cue& c = cues[cueCount];
    unsigned long newId = obj["id"] | 0UL;
    c.id = (newId > 0) ? newId : (unsigned long)millis() + cueCount;
    strlcpy(c.name, obj["name"] | "Cue", sizeof(c.name));
    c.r    = constrain((int)(obj["r"]    | 0),   0, 255);
    c.g    = constrain((int)(obj["g"]    | 0),   0, 255);
    c.b    = constrain((int)(obj["b"]    | 0),   0, 255);
    c.w    = constrain((int)(obj["w"]    | 0),   0, 255);
    c.pan  = constrain((int)(obj["pan"]  | 90),  0, 180);
    c.tilt = constrain((int)(obj["tilt"] | 90),  0, 180);
    c.targetCount = 0;
    JsonArray ft = obj["fixTargets"].as<JsonArray>();
    if (!ft.isNull()) for (JsonVariant v : ft) {
      if (c.targetCount >= MAX_TARGETS) break;
      c.fixTargets[c.targetCount++] = v.as<int>();
    }
    if (c.targetCount == 0) { c.fixTargets[0] = 0; c.targetCount = 1; }
    cueCount++;
  }
  saveCuesToFlash();
  sendJson(200, "{\"status\":\"ok\",\"count\":" + String(cueCount) + "}");
}

void handleRoot()           { server.sendHeader("Access-Control-Allow-Origin","*"); server.send_P(200,"text/html",INDEX_HTML); }
void handleDiscoveryPanel() { server.sendHeader("Access-Control-Allow-Origin","*"); server.send_P(200,"text/html",DISCOVERY_PANEL_HTML); }
void handleStatus()     { sendJson(200,"{\"connected\":true,\"port\":\"WiFi\",\"ip\":\""+WiFi.localIP().toString()+"\"}"); }
void handlePorts()      { sendJson(200,"[{\"port\":\"WiFi\",\"description\":\"ESP32 @ "+WiFi.localIP().toString()+"\"}]"); }
void handleConnect()    { sendJson(200,"{\"status\":\"ok\",\"port\":\"WiFi\"}"); }
void handleDisconnect() { sendJson(200,"{\"status\":\"ok\"}"); }
void handleSeqStop()    { seqRunning=false; sendJson(200,"{\"status\":\"ok\"}"); }
void handleSeqStatus()  { sendJson(200,String("{\"running\":"+(seqRunning?String("true"):String("false"))+"}")); }
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

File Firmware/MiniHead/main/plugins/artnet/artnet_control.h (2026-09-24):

#pragma once

// ── Art-Net Control ───────────────────────────────────────────────
// HTTP API routes for Art-Net patch management.
// LittleFS JSON storage for patch records (/artnet.json).
//
// Included from wifi_control.h, which owns `server`, `sendJson`,
// `_getBody`, and `_bodyAccumulator`.
//
// Each ESP stores exactly ONE patch — its own universe + startAddr.
// fixID is NOT stored on the ESP; the PC App uses fixID to route
// HTTP POSTs to the right ESP's IP.
// ─────────────────────────────────────────────────────────────────

#include "artnet_globals.h"
#include "artnet_receiver.h"

// ── Upsert helper — overwrite own patch ──────────────────────────
// artnet_savePatches() and artnet_loadPatches() live in artnet_receiver.h
// so they are available on ALL nodes (leader + follower).
void artnet_upsertPatch(uint16_t universe, uint16_t startAddr) {
  if (universe > 32767) {
    Serial.println("[ArtNet] upsertPatch: universe > 32767 rejected");
    return;
  }
  artnetPatches[0].universe  = universe;
  artnetPatches[0].startAddr = startAddr;
  artnetPatchCount = 1;
  artnet_savePatches();
}

// ── JSON serialiser ───────────────────────────────────────────────
// Include fixID in the API response for UI display (panels use it to
// match patches to fixtures in the network view). Not stored on disk.
String artnetPatchToJson(const ArtnetPatch& p) {
  return "{\"fixID\":" + String(ownFixID) +
         ",\"universe\":" + String(p.universe) +
         ",\"startAddr\":" + String(p.startAddr) + "}";
}

// ── HTTP handlers ─────────────────────────────────────────────────

void handleArtnetStatus(AsyncWebServerRequest* req) {
  // Include live channel values so the web UI can display them in the Art-Net bar
  String json = "{\"active\":";
  json += artnetActive ? "true" : "false";
  json += ",\"patchCount\":" + String(artnetPatchCount);
  json += ",\"r\":"    + String(curR);
  json += ",\"g\":"    + String(curG);
  json += ",\"b\":"    + String(curB);
  json += ",\"w\":"    + String(curW);
  json += ",\"pan\":"  + String(curPan);
  json += ",\"tilt\":" + String(curTilt);
  json += "}";
  sendJson(req, 200, json);
}

void handleGetArtnetPatch(AsyncWebServerRequest* req) {
  String json = "[";
  for (int i = 0; i < artnetPatchCount; i++) {
    if (i > 0) json += ",";
    json += artnetPatchToJson(artnetPatches[i]);
  }
  json += "]";
  sendJson(req, 200, json);
}

// POST /api/artnet/patch  {universe, startAddr}  (fixID accepted but ignored)
void handlePostArtnetPatch(AsyncWebServerRequest* req) {
  JsonDocument doc;
  if (deserializeJson(doc, _getBody(req))) {
    sendJson(req, 400, "{\"status\":\"error\",\"message\":\"Bad JSON\"}");
    return;
  }
  int universe  = doc["universe"]  | 0;
  int startAddr = doc["startAddr"] | 1;
  if (universe < 0 || universe > 32767) {
    sendJson(req, 400, "{\"status\":\"error\",\"message\":\"Invalid universe — must be 0–32767\"}");
    return;
  }
  if (startAddr < 1 || startAddr + DMX_FOOTPRINT - 1 > DMX_CHANNELS) {
    sendJson(req, 400, "{\"status\":\"error\",\"message\":\"Invalid startAddr\"}");
    return;
  }
  artnet_upsertPatch((uint16_t)universe, (uint16_t)startAddr);
  sendJson(req, 200, "{\"status\":\"ok\"}");
}

// PUT /api/artnet/patch/*  — update universe / startAddr of own patch
void handleUpdateArtnetPatch(AsyncWebServerRequest* req) {
  if (artnetPatchCount == 0) {
    sendJson(req, 404, "{\"status\":\"error\",\"message\":\"No patch configured\"}"); return;
  }
  JsonDocument doc;
  if (deserializeJson(doc, _getBody(req))) {
    sendJson(req, 400, "{\"status\":\"error\",\"message\":\"Bad JSON\"}"); return;
  }
  int universe  = doc["universe"]  | -1;
  int startAddr = doc["startAddr"] | -1;
  if (universe  >= 0 && universe <= 32767) artnetPatches[0].universe = (uint16_t)universe;
  if (startAddr >= 1 && startAddr + DMX_FOOTPRINT - 1 <= DMX_CHANNELS)
    artnetPatches[0].startAddr = (uint16_t)startAddr;
  artnet_savePatches();
  sendJson(req, 200, "{\"status\":\"ok\"}");
}

// DELETE /api/artnet/patch/*  — clear own patch
void handleDeleteArtnetPatch(AsyncWebServerRequest* req) {
  artnetPatchCount = 0;
  artnet_savePatches();
  sendJson(req, 200, "{\"status\":\"ok\"}");
}

// ── Clear all patches ─────────────────────────────────────────────
void handleClearAllArtnetPatches(AsyncWebServerRequest* req) {
  artnetPatchCount = 0;
  artnet_savePatches();
  sendJson(req, 200, "{\"status\":\"ok\",\"removed\":1}");
}

// ── Clear patches for one universe ───────────────────────────────
void handleClearUniverseArtnetPatches(AsyncWebServerRequest* req) {
  String path = req->url();
  int uni = path.substring(path.lastIndexOf('/') + 1).toInt();
  bool removed = false;
  if (artnetPatchCount > 0 && (int)artnetPatches[0].universe == uni) {
    artnetPatchCount = 0;
    artnet_savePatches();
    removed = true;
  }
  sendJson(req, 200, String("{\"status\":\"ok\",\"removed\":") + (removed ? "1" : "0") + "}");
}

// ── Bulk patch — apply own slice only ────────────────────────────
// The PC App handles pushing to other ESPs individually.
// This endpoint lets the ESP web UI set up the whole show from one
// request; the ESP stores only its own entry from the bulk range.
void handleBulkArtnetPatch(AsyncWebServerRequest* req) {
  JsonDocument doc;
  if (deserializeJson(doc, _getBody(req))) {
    sendJson(req, 400, "{\"status\":\"error\",\"message\":\"Bad JSON\"}");
    return;
  }
  int universe   = doc["universe"]   | 0;
  int startAddr  = doc["startAddr"]  | 1;
  int count      = doc["count"]      | 0;
  int firstFixID = doc["firstFixID"] | 1;

  if (universe < 0 || universe > 32767) {
    sendJson(req, 400, "{\"status\":\"error\",\"message\":\"Invalid universe — must be 0–32767\"}");
    return;
  }
  if (count <= 0 || firstFixID <= 0 || startAddr < 1) {
    sendJson(req, 400, "{\"status\":\"error\",\"message\":\"Invalid parameters\"}");
    return;
  }
  for (int n = 0; n < count; n++) {
    int fixID = firstFixID + n;
    int addr  = startAddr + n * DMX_FOOTPRINT;
    int uni   = universe;
    while (addr + DMX_FOOTPRINT - 1 > DMX_CHANNELS) { uni++; addr -= DMX_CHANNELS; }
    if (addr < 1) addr = 1;
    if (fixID == ownFixID) {
      // This is our slice — store it.
      artnet_upsertPatch((uint16_t)uni, (uint16_t)addr);
      break;
    }
  }
  sendJson(req, 200, "{\"status\":\"ok\",\"count\":" + String(count) + "}");
}
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

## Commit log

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2026-04-12 feat: FixID-based cue targets + fader controls selected heads
    - Cue struct changed from MAC-string targets to int fixTargets[] (FixID
    array). FixID 0 = broadcast all. NVS version bumped to 2 so old flash
    cues are cleared automatically on first boot.
    - fireCueToTargets() now resolves FixIDs at fire time, so any ESP that
    later takes over a FixID automatically receives those cues.
    - Discovery panel exposes nh_getSelectedMACs() and nh_getSelectedFixIDs()
    to the main page so other UI components can read the current selection.
    - sendCurrent() (fader debounce) now sends to all checked heads in the
    Network Heads list instead of self only.
    - saveCue() / nh_addToCue() send fixTargets; cue ca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
    [wifi_control.h]
2026-04-12 feat: fixture names, offline fixture pool, cue target editor
    Beacon protocol:
    - Extended to 6 fields: MINIHEAD|MAC|IP|FixID|ROLE|NAME (backwards-compat)
    - ESP stores/loads ownName in NVS; SETNAME UDP command updates it remotely
    Firmware:
    - discovery_globals.h: name[32] field added to Peer struct, ownName extern
    - discovery.h: discovery_loadName/saveName, extended send/parse, addOrUpdate accepts name
    - udp_control.h: udp_sendSetName() + SETNAME: handler
    - wifi_control.h: name in /api/heads, POST /api/heads/<mac>/name,
    GET /api/fixtures (non-persistent, returns known heads with fixID>0)
    PC app:
    - pc_fixtures.json: persistent fixture pool (id, name, mac)
    - Auto-registers beaconing devices i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
    [wifi_control.h]
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2026-04-13 fix: restore LED color correctly after identify/rainbow effects
    - IDENTIFY_ON saves curR/G/B/W before going white; OFF/watchdog restore from saved values
    - RAINBOW:1 saves current color before loop; RAINBOW:0 restores it
    - Cue list: HTML5 drag-and-drop reordering with grab handle and highlight
    - Add PUT /api/cues/reorder endpoint in wifi_control.h
    [core.h, wifi_control.h]
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2026-04-13 fix: move artnet_control.h include after sendJson in wifi_control.h
    artnet_control.h uses `server` and `sendJson()` which are defined
    mid-file. Moving the include to after those definitions fixes the
    'sendJson was not declared in this scope' compile error.
    Also add SETPATCH: UDP command handler + artnet_upsertPatch forward
    declaration to udp_control.h (v2), and apply the same wifi_control.h
    fix to v3.
    [wifi_control.h]
2026-04-13 fix(discovery): leader switch, editable DMX patch sidebar, larger grid IDs, DMX column in heads
    - discovery.h: add periodic loop check so ESP immediately yields to
    a better leader (lower MAC) even when beacon is missed
    - artnet_control.h: add PUT /api/artnet/patch/:fixID to update
    universe/startAddr of an existing patch in-place
    - wifi_control.h: register PUT route in onNotFound handler
    - artnet_panel_html.h: grid cell font-size 6→9px; patch table rows now
    have editable Universe/Addr number inputs with live PUT updates
    - html_page.h: new 'artpatch' grid area below Serial in right sidebar
    renders patch list with editable fields + 3s live refresh;
    ap-table/ap-num/ap-del CSS added
    -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
    [artnet_control.h, wifi_control.h]
2026-04-14 feat(v4): WiFi AP fallback, standalone/follower modes, cue export/import, Art-Net no-patch blink
    - New wifi_manager.h: connects via NVS creds (priority) or config.h fallback,
    starts AP "MiniHead-XXXXXX" (PW: minihead) with captive portal on failure
    - New wifi_captive_html.h: WiFi config portal with network scanner
    - New NodeRole enum: ROLE_AP_PORTAL, ROLE_STANDALONE, ROLE_FOLLOWER (no ESP self-elects)
    - Rewritten discovery.h: only PC can be leader; ESPs switch STANDALONE↔FOLLOWER dynamically
    - wifi_control.h: added /api/mode, /api/cues/export (JSON download), /api/cues/import
    - html_page.h: mode label in header, Export/Import buttons in Cues panel
    - artnet_receiver.h: non-blocking 250ms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
    [artnet_control.h, artnet_globals.h, artnet_receiver.h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]
2026-04-20 feat(v4.2): clean rebuild from v3 — LittleFS storage, ArtnetWifi, PC App Art-Net patch
    Firmware — nano_moving_light_modular_v4_2 (v4 replaced):
    - Replace all NVS/Preferences usage with central LittleFS+JSON storage layer (storage.h)
    - Rebuild Art-Net receiver using rstephan/ArtnetWifi library (removes 30-line manual UDP parser)
    - Add FIRMWARE_VERSION startup print to all 6 firmware versions
    - Add dedicated README to every firmware version folder
    - Fix mobile layout: artpatch grid-area missing from html_page.h grid-template-areas
    PC App:
    - Add APP_VERSION "PC App v4.2" + /api/version endpoint
    - Add full Art-Net patch CRUD API backed by pc_artnet_patch.json
    - Add Art-Net panel UI (plugins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
    [artnet_control.h, artnet_globals.h, artnet_receiver.h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]
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2026-04-22 feat(v4.2): merge PC App UI into ESP, CLEAR endpoints, SET FIX IDs mode
    - artnet_control.h: add DELETE /api/artnet/patch (clear all) and
    DELETE /api/artnet/patch/universe/<uni> (clear universe) handlers
    - wifi_control.h: register new DELETE routes; universe handler takes
    priority over generic patch/:fixID handler in onNotFound
    - artnet_panel_html.h: PATCH SELECTED (from Network Heads selection),
    CLEAR UNI / CLEAR ALL buttons, conflict detection popup
    (OVERWRITE / MERGE / CANCEL) with overlap check across current patches
    - discovery_panel_html.h: SET FIX IDs mode with patch bar and DONE
    (batch-assign sequential Fix IDs to selected heads in sorted order),
    NO FIX# / NO DMX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
    [2604221950-Assembly-AssemblyBody001.step, Joint-v1.step]
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2026-04-23 feat(v4.2): WiFi multi-network list with last-connected priority
    Replace single WIFI_SSID/WIFI_PASSWORD defines with a WifiCredential
    struct array in config.h/config.example.h. main.ino now scans first,
    tries the last-connected SSID (persisted in /wifi_last.json) before
    falling back to other list entries, retries on failure.
    [2604222109-Assembly-AssemblyBody001-Bottom.step, 2604222109-Assembly-AssemblyBody001-Top.step, 2604222139-Yoke-Body.step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]
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2026-04-23 feat(v4.2): migrate WebServer → ESPAsyncWebServer (non-blocking HTTP)
    Servo commands from the web UI were delayed or lost because the
    synchronous WebServer blocked handleClient() while serving large
    PROGMEM panel HTML responses (up to ~200 ms per request).
    Replaced WebServer with ESPAsyncWebServer:
    - HTTP requests are handled on the WiFi FreeRTOS task (prio 23),
    completely independent of the main Arduino loop()
    - /api/send reaches applyCommand() immediately, regardless of any
    concurrent HTML page loads
    - Removed server.handleClient() from wifi_control_loop() — loop is
    now free for sequencer / motion only
    - Body accumulation via request->_tempObject (_bodyAccumulator helper)
    - send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
    [artnet_control.h, wifi_control.h]
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2026-04-23 fix: acquire TCPIP core lock before server.begin() (ESP-IDF 5.x)
    tcp_alloc() asserts that LOCK_TCPIP_CORE is held in IDF 5.x.
    The Arduino loopTask does not hold it automatically — wrap
    server.begin() with LOCK_TCPIP_CORE() / UNLOCK_TCPIP_CORE()
    from lwip/tcpip.h to satisfy the assertion.
    [wifi_control.h]
2026-04-24 fix: replace LOCK_TCPIP_CORE with esp_netif_tcpip_exec; fix PC App beacon + patch sync
    ESP firmware (wifi_control.h):
    - Replace LOCK_TCPIP_CORE()/UNLOCK_TCPIP_CORE() with esp_netif_tcpip_exec() for
    server.begin() — correct IDF 5.x approach that avoids the deadlock caused by
    holding the lock while AsyncTCP's internal callbacks need the lwIP task queue.
    PC App (pc_leader.py):
    - Fix [Errno 65] beacon error on macOS: replace "<broadcast>" with computed
    subnet broadcast address (e.g. 192.168.178.255 derived from own IP).
    - Add push_patch_to_esp() helper: sends SETPATCH UDP command to the ESP
    follower that owns a given fixID whenever a patch is added, updated, or
    bulk-assigned — ens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
    [wifi_control.h]
2026-04-24 fix(artnet): replace ArtnetWifi with AsyncUDP — no library dependency
    ArtnetWifi's WiFiUDP::begin() fails silently on ESP32-C3 with Arduino
    Core 3.x (IDF 5.x), so no packets were ever received despite the socket
    appearing to open. AsyncUDP is built into the Arduino Core, runs its
    callback on the WiFi task (no loop polling), and has no IDF version issues.
    Changes:
    - artnet_receiver.h: remove ArtnetWifi dependency, add AsyncUDP listener
    with manual ArtDmx packet parser (ID, opcode, universe, length, data).
    artnet_receiver_loop() no longer needs to poll — only handles timeout.
    - core.h: update FIRMWARE_VERSION string
    - README.md: remove ArtnetWifi from library table, update references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
    [artnet_receiver.h, core.h]
2026-04-24 fix: WiFiUDP polling for Art-Net; subnet broadcast for ESP beacons
    artnet_receiver.h:
    - Replace AsyncUDP (unreliable on ESP32-C3/IDF 5.x) with WiFiUDP polling,
    identical pattern to the working udp_control.h (port 4211). Uses
    parsePacket()/read() in artnet_receiver_loop(); all parsing logic unchanged.
    discovery.h:
    - Replace 255.255.255.255 (limited broadcast) with directed subnet broadcast
    calculated from WiFi.localIP() + WiFi.subnetMask() (e.g. 192.168.178.255).
    Fritz!Box doesn't forward limited broadcasts across WiFi→Ethernet; directed
    broadcast routes correctly. Matches the fix already applied to pc_leader.py.
    [artnet_receiver.h]
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2026-04-25 fix(artnet): load patches at boot on ALL nodes (leader + follower)
    artnet_loadPatches() was only reachable via artnet_control_setup() →
    wifi_control_setup(), which is skipped for follower nodes. Follower ESPs
    therefore booted with artnetPatchCount=0 and silently ignored every Art-Net
    frame.
    Fix: move artnet_savePatches()/artnet_loadPatches() up into artnet_receiver.h
    (included by every node) and call artnet_loadPatches() from
    artnet_receiver_setup(). Art-Net now works immediately on followers from the
    first packet, using the patch saved to /artnet.json in a prior session.
    SETPATCH from the PC leader continues to update patches in memory and persist
    them via artnet_upsertPatch() as before.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
    [artnet_control.h, artnet_receiver.h]
2026-04-27 feat(v4.2): unified data, DMX overlap guard, follower web server, rainbow fix
    - Merge pc_fixtures.json + pc_artnet_patch.json + pc_mac_names.json into
    single pc_data.json; auto-migrates legacy files on first run
    - Add DMX overlap detection (409 + toast) — two fixtures can no longer share
    the same 7-channel window on the same universe
    - ACK checkmark only shown after explicit user edits (not auto re-join pushes);
    display extended to 20 s
    - New log-flags panel (plugins/log/)
    - core.h: applyCommand uses hasColor flag — pure PAN/TILT commands no longer
    stop rainbow or black out LED
    - artnet_receiver.h: save pre-ArtNet LED/servo state on first packet; restore
    it o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
    [artnet_receiver.h, core.h]
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2026-05-27 feat: ArtNet patch sync + v1 network panel inline + firmware refactor
    PC APP v1:
    - Inline network heads panel in index.html — eliminates loadModule() race condition and Werkzeug threading deadlock
    - Add EDIT/SAVE mode to freeze table refresh while typing
    - Fix patch column logic (UDP heads get +DMX button, not grey dashes)
    - Switch server to waitress (threaded) so concurrent API requests don't block
    - Remove loadModule call for discovery panel from app.js
    PC APP v2 (new):
    - Full v2 app added (server.py, index.html, css, js)
    - server.py: push ArtNet patches to ESP via HTTP on create/update/delete
    - server.py: auto-sync patch on ESP beacon join
    Firmware v4.2:
    - Refactor udp_control into it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
    [202605122300-Yoke.step, 202605131130-Base-Top.step, 202605131130-Head-Bottom.step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]
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2026-05-27 fix(firmware): ESP UI 270° sliders, ArtNet rainbow coexistence, peer timeout alignment
    - html_page.h: PAN/TILT sliders max 180→270°, defaults 90→135° (closes #18 ESP UDP UI)
    - artnet_receiver.h: ArtNet no longer kills rainbow — drives servos always,
    skips setLED() when rainbowActive; coexistence comment added
    - discovery_globals.h: LEADER_TIMEOUT_MS 30000→90000 to match PC PEER_TIMEOUT (closes #16)
    [artnet_receiver.h]
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2026-05-27 fix(firmware): ArtNet self-contained per-ESP, beacon includes MODE field
    - Remove artnet_relayToFollowers() — each ESP receives ArtNet directly on
    port 6454 and handles its own patch; no relay chain needed
    - artnetActive / pre-state save / "Active" log now only fire when a packet
    matches the own fixID+universe patch, not for any arriving universe
    - Remove #ifdef PLUGIN_ARTNET distinction — all ESPs behave identically:
    keep only own fixID patch, apply own data, never relay
    - Remove udp_sendCommand forward-declare (nothing sends UDP from here now)
    - Update file header comment to reflect new architecture
    - Beacon now sends 7 fields: MINIHEAD|MAC|IP|fix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
    [artnet_receiver.h]
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2026-05-27 fix(firmware): log ArtNet packet arrival regardless of patch match
    After the artnetActive refactor, packets arriving with no matching patch
    were completely silent — indistinguishable from "no packets at all".
    artnet_onDmxFrame() now logs once per new universe (gated by artnetEvents):
    [ArtNet] Packet received — universe 1 (own patch: U1 Fix#1)
    This fires before the patch check, so the user can tell:
    - No log at all → packets not reaching the ESP (network/IP issue)
    - "Packet received" but no "Active" → universe or fixID mismatch in patch
    [artnet_receiver.h]
2026-05-27 firmware: remove fixID from ArtNet patch — each ESP stores own patch only
    fixID in ArtnetPatch was a relay-era concept: the leader stored patches
    for all fixtures and filtered by fixID at apply-time. With relay removed,
    each ESP only ever holds its own patch (universe + startAddr). The
    `p.fixID != ownFixID` guard became a silent footgun — a mismatched fixID
    would cause ArtNet to silently stop working.
    - ArtnetPatch struct: remove int fixID field
    - artnet_receiver: save/load JSON without fixID, remove both fixID
    filters (setup-time and apply-time), update log lines
    - artnet_control: artnet_upsertPatch(universe, startAddr) — no fixID;
    POST overwrites single own patch; PUT/D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
    [artnet_control.h, artnet_globals.h, artnet_receiver.h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]
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2026-05-29 fix(core): smooth servo motion + skip redundant LED updates
    Servo smoothing:
    - setPan/setTilt now write to a float target; core_loop advances toward
    it at 200°/s (4° per 20ms step). ArtNet timing jitter no longer
    produces servo jerks — irregular packet spacing gets absorbed.
    - SLEW constant can be tuned: higher = snappier, lower = smoother.
    LED optimisation:
    - setLED skips strip.show() when RGBW values are unchanged. NeoPixel
    show() briefly disables interrupts; calling it 44×/s at identical
    values wasted CPU and added timing noise.
    [core.h]
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2026-05-29 fix(wifi): disable modem sleep for reliable UDP reception
    ESP32-C3 WiFi modem sleep was causing ~60% packet loss on high-rate UDP
    (ArtNet at 44 Hz). With sleep enabled the radio powers down between
    beacon intervals and misses incoming unicast packets.
    WiFi.setSleep(false) keeps the radio active at all times.
    Trades a few mA extra current draw for reliable ArtNet delivery.
    [main.ino]
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2026-05-29 fix(core): exponential servo smoothing — professional ease-out motion
    Replace linear slew rate with exponential smoothing (IIR low-pass):
    next = current + SMOOTH × (target − current)
    This is the same technique used in professional moving head fixtures:
    - Natural ease-out: fast approach when far, gentle on arrival
    - Automatically absorbs ArtNet packet timing jitter
    - No hard speed cap means no abrupt stops mid-movement
    SERVO_SMOOTH = 0.12 → ~133ms time constant at 50 Hz.
    Tune lower (0.05) for silkier slow movements, higher (0.3) for snappy.
    [core.h]
2026-05-29 fix(core): only write servo PWM when position actually changed
    Exponential smoothing produces endless micro-corrections — writeMicroseconds
    was called every 20ms even at rest, keeping the motor constantly energised
    and hot. Now only writes when the integer µs value changes, so a settled
    servo gets no new commands and its motor can relax.
    [core.h]
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2026-05-31 fix: 4 issues found in code review
    1. Remove duplicate setupConfigRoutes() call in ArtNet wifi_control_setup()
    — setupRoutes() already calls it internally, causing double registration.
    2. Stop demoActive when cue fires or handleSend executes — previously only
    rainbowActive was cleared, letting demo immediately override cue colors.
    3. Add demo-btn CSS in theme.h — teal/purple gradient with active animation,
    matching the rainbow-btn style.
    4. Fix speed label × symbol (was plain 'x').
    [wifi_control.h]
2026-05-31 fix #18 #21: servo deadband + startup animation plugin
    Fixes #18 — Tilt servo hunting/overshooting:
    Added SERVO_DEADBAND (1.5°) to the exponential smoothing loop.
    Smoothing stops once within the deadband, preventing the motor from
    oscillating when it lacks torque to close the last fraction of a degree.
    Fixes #21 — Startup animation missing:
    Rewrote startup_animation.h: servo calibration sweep (0°→270°→135°)
    matching real fixture power-on behaviour, followed by R→G→B color test.
    Uses direct servoPan/servoTilt writes (bypassing exponential smoothing)
    because setup() runs before core_loop() starts. Smoothing state is synced
    at the end so core_loop() picks up cle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
    [core.h]
2026-05-31 fix: full codebase audit — 10 issues resolved
    [FW-1] Cue pan/tilt clamped to 0-180° despite 270° servo range — data
    loss on save/reload. Changed both constrain() calls to 0-270.
    [FW-2] Rainbow hue accumulator not reset when demo stops. Added
    rainbowHue=0 and _rainbowHueF=0 in the DEMO: command branch so
    rainbow always starts fresh.
    [FW-3] Sequencer state not cleared on leader→follower role change.
    Added seqRunning/seqIndex/seqIdCount reset in wifi_control_stop().
    [FW-4] Peer table silently rejects ESPs when full. Added a Serial warning
    when peerCount hits MAX_PEERS in discovery_addOrUpdate().
    [FW-5] Dead stub udp_sendSe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
    [core.h, wifi_control.h]
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2026-06-01 feat: WiFi AP fallback — hotspot after 2 failed scan cycles
    When no known WiFi network is reachable after 2 full scan cycles the ESP
    starts an open hotspot instead of looping forever on a red LED:
    SSID: MiniHead-XXXXXX (last 3 MAC bytes, e.g. MiniHead-BF0DE8)
    Password: none (open)
    IP: 192.168.4.1 (ESP32 default softAP address)
    LED shows slow blue pulse × 3 then stays dim blue so the user knows
    to connect to the hotspot. The full web UI loads at http://192.168.4.1.
    Also fixes WiFi.localIP() returning 0.0.0.0 in AP mode — /api/status,
    /api/ports, and the serial log now fall back to softAPIP().
    [main.ino, wifi_control.h]
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2026-06-01 feat: AP hotspot password — set/clear in web UI, warning when open
    - AP password persisted to /ap_config.json (LittleFS); survives reboot
    - On AP start, loads saved password and passes to WiFi.softAP()
    - POST /api/ap/password {password} — validates ≥8 chars, saves, restarts
    softAP with new credentials; returns {reconnect:true} so browser warns
    - Red warning banner in page header when AP mode + no password set
    - '// AP Settings' panel (hidden in STA mode) lets user set/clear password
    directly from the web UI — appears before Log Config section
    - /api/status now includes apMode and apPasswordSet fields
    [main.ino, wifi_control.h]
2026-06-01 refactor: AP password as compile-time constant in config.h
    Replace the dynamic LittleFS-based password management (flash storage,
    HTTP endpoint, web UI panel, warning banner) with a simple #define in
    config.h — same pattern as WiFi credentials.
    #define AP_PASSWORD "minihead" // ≥8 chars, or "" for open
    config.example.h updated with the same constant and comment.
    All runtime password management code removed.
    [main.ino, wifi_control.h]
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2026-06-01 fix: SSID last 2 hex digits only + captive portal opens in browser
    - SSID: MiniHead-XX where XX = last byte of MAC (2 hex chars, e.g. MiniHead-E8)
    Was incorrectly using 3 bytes (6 chars)
    - Captive portal button: added target='_blank' so iOS opens the controller
    in Safari instead of staying inside the captive portal mini-browser
    [main.ino, wifi_control.h]
2026-06-01 fix: SSID last 4 hex chars + captive portal opens system browser
    - SSID: MiniHead-XXYY where XXYY = last 2 bytes of MAC (4 hex chars)
    - Captive portal button: window.open() + target=_blank to force iOS
    to open the system browser instead of staying in the CNA popup
    [main.ino, wifi_control.h]
2026-06-01 fix: read MAC after WiFi.mode(WIFI_AP) to get correct SSID
    WiFi.macAddress() called during failed STA connection attempts returns
    garbage (0xA5A5) because the radio is in a broken state after repeated
    connect/disconnect cycles. Moving the read to after mode(WIFI_AP)+100ms
    settle gives the real MAC → correct SSID e.g. MiniHead-0DE8.
    [main.ino]
2026-06-01 fix: iOS captive portal WISPr two-step — opens Safari correctly
    target="_blank" and window.open() inside iOS CNA are blocked until iOS
    considers the network "connected". Fix: WISPr two-step handshake.
    Step 1: serve CNA page with "Open Controller" link + JS timer (1500 ms)
    that navigates to /hotspot-detect.html?success
    Step 2: when ?success is requested, return exactly:
    <HTML><HEAD><TITLE>Success</TITLE></HEAD><BODY>Success</BODY></HTML>
    iOS receives this → marks network connected → link opens Safari ✓
    The 1500 ms window lets the user tap before the page changes.
    Once iOS marks connected (after step 2), the link always opens Safari.
    [wifi_control.h]
2026-06-01 fix: use esp_efuse_mac_get_default() for stable AP SSID
    WiFi.macAddress() during AP mode transition could return garbage,
    causing the SSID to change between reflashes. The eFuse MAC is
    hardware-permanent — reads directly from chip, bypasses WiFi stack,
    always returns the same value regardless of mode or connection state.
    [main.ino]
2026-06-01 fix: suppress iOS/Android captive portal popup in AP mode
    Returning the correct "Success" / 204 / connecttest responses to OS
    probe URLs makes iOS/Android think the network has internet → no CNA
    popup appears at all → hotspot connects silently → user opens Safari
    and navigates to 192.168.4.1 or minihead.local manually.
    [wifi_control.h]
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2026-06-01 fix: use WiFi.macAddress() for AP SSID — consistent with PC app and UDP identity
    [main.ino]
2026-06-01 fix: read MAC once at boot into deviceMAC global — SSID stays stable
    WiFi.macAddress() returns different values depending on which WiFi
    interface is active. Reading it once in STA mode before any mode changes
    and storing it in deviceMAC ensures the SSID is identical at boot and
    after AP password changes.
    [main.ino, wifi_control.h]
2026-06-01 feat: ESP-NOW provisioning, startup animation rework, README overhaul
    - Add espnow_provision plugin: SEEKER/SENDER roles, AES-128-CBC + HMAC-SHA256
    encrypted credential distribution, 64-entry nonce replay protection
    - Add pre-wifi hook in main.ino + /wifi_provision.json credential flow
    - Stretch startup animation to ~10 s with smooth servo interpolation (_sa_sweepTo)
    - Rewrite README with full API reference, mode explanations, library list,
    theme system docs, LittleFS file table, and Serial Monitor boot output
    [main.ino]
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
